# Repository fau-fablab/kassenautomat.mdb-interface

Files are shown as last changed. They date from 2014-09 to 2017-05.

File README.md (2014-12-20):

kassenautomat.mdb-interface
===========================

MDB to USB Interface für Münzwechsler-Ansteuerung

FTDI-Konfiguration
------------------
 * es kommt ein FT232RL zum Einsatz
 * Tool für Linux: https://github.com/mehlis/ft232r_prog.git
 * sonst FT_PROG
 * Linuxzeile: `./ft232r_prog --product 'MDB Interface' --manufacturer 'FAU FabLab' --cbus0 TxLED --cbus1 RxLED --cbus2 Clk12`

Atmel
-----
  * `make fuse` (zur Zeit für external clock via FTDI)
  *  http://www.engbedded.com/fusecalc/
  *  Wenn die Fuses auf externen Takt gesetzt sind, läuft der Chip nur, solange kein USB suspend ist - screen offen halten! (wirklich? nicht jeder hat usb autosuspend an.)
  * `make program`

Sicherung 12V-Schiene
---------------------
  * im worst case sollte eine 5A mtltrg. Sicherung für die 12V-Schiene reichen

Aktueller Stand Platine
-----------------------
  * Kommunikation Atmel <-> PC -> MDB geht, MDB -> PC sollte in rev2 auch gehen.
  * RX- und TX-LEDs am FT232RL gehen nicht (TM)

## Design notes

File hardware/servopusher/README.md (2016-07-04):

servopusher
-----------

The coin-accepting mechanism sometime jams. In this case a lever on top of it has to be pushed.

For this a small system is used which pushes the lever with a servo after the user pushes a switch on the outside of the cash terminal.

After triggering the switch, the microcontroller deactivates the interrupts and drives the servo from position 0 into position 1.
Upon arrival the system starts the return to position 0. Position 0 does not push the lever while position 1 does.

The outside momentary switch is a vandalism safe one with an LED ring. The system could flash the LED ring as a "DONE"-indicator. 

####arduinodruecker
In order to get things done, I have quickly scrambled an Arduino together. The ino-file is in arduinodruecker and self-explinatory.

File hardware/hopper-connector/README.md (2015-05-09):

This is a connector-PCB between coin hopper and mdb-interface-PCB.

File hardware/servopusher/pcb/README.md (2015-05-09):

This directory contains the plans for the PCB.

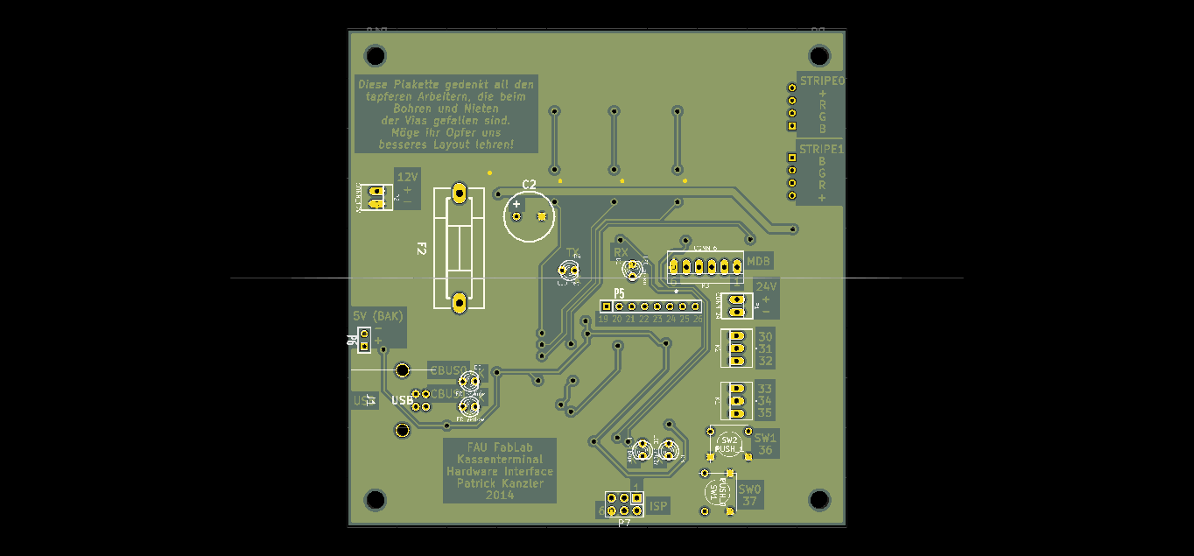
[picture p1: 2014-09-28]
hardware/mdb-interface/plot/cad/mdb-interface_b.png

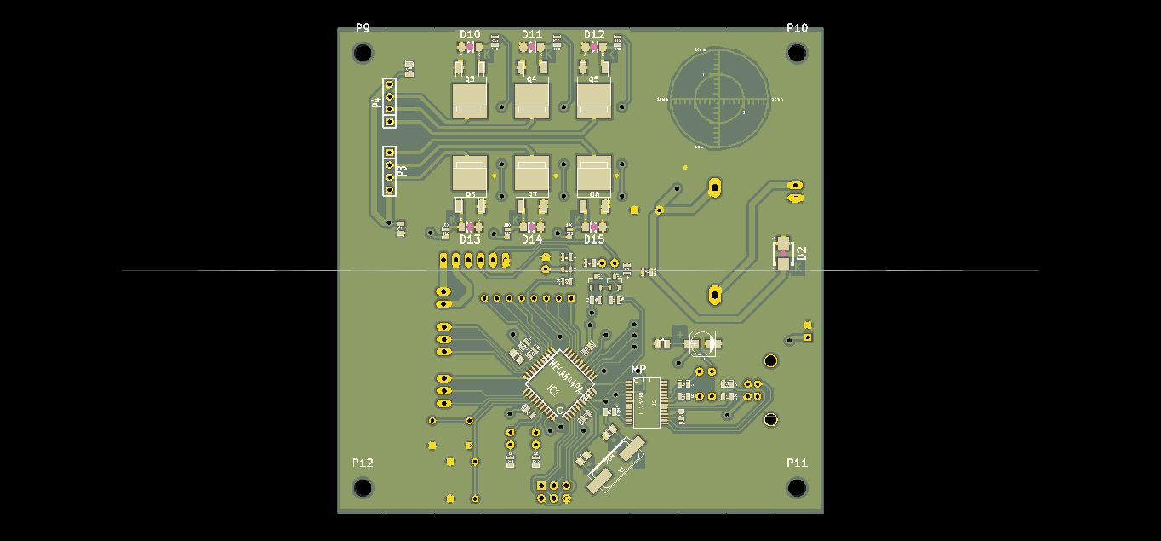
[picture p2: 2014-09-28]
hardware/mdb-interface/plot/cad/mdb-interface_f.png

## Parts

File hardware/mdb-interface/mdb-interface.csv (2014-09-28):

Id | Bezeichner | Gehäuse | Stückzahl | Bezeichnung | Anbieter und Ref
1 | C1 | SMD_Packages:SM0603_Capa | 1 | 10n
2 | C2 | Capacitors_Elko_ThroughHole:Elko_vert_DM10_RM5_CopperClear | 1 | 470u
3 | C3 | Capacitors_SMD:c_elec_5x5.8 | 1 | * 47u 6,3V
4 | C4,C7,C11,C12,C13,C15 | SMD_Packages:SM0603_Capa | 6 | 100n
5 | C5,C14 | Capacitors_SMD:c_0805 | 2 | 1u
6 | C9,C10 | Capacitors_SMD:c_0805 | 2 | 22p
7 | D2 | Diodes_SMD:Diode-SMB_Standard | 1 | SM6T15A
8 | D10,D11,D12,D13,D14,D15 | Diodes_SMD:Diode-MiniMELF_Standard | 6 | ZD5.1
9 | F2 | Fuse_Holders_and_Fuses:Fuseholder5x20_horiz_SemiClosed_Casing10x25mm | 1 | FUSE
10 | ferrite1 | SMD_Packages:SM0603_Resistor | 1 | 0
11 | IC1 | SMD_Packages:TQFP44 | 1 | ATMEGA644PA-A
12 | J1 | Connect:USB_B | 1 | USB
13 | K1,K2 | Connect:PINHEAD1-3 | 2 | *
14 | P1 | Connect:PINHEAD1-2 | 1 | CONN_24
15 | P2 | Connect:PINHEAD1-2 | 1 | CONN_12V
16 | P3 | Connect:PINHEAD1-6 | 1 | CONN_6
17 | P4,P8 | Connect:SIL-4 | 2 | CONN_4
18 | P5 | Connect:SIL-8 | 1 | *
19 | P6 | Connect:SIL-2 | 1 | *
20 | P7 | Pin_Headers:Pin_Header_Straight_2x03 | 1 | CONN_6
21 | P9,P10,P11,P12 | Mounting_Holes:MountingHole_3-7mm | 4 | CONN_1
22 | Q1,Q2 | Transistors_SMD:sot23 | 2 | BCW67
23 | Q3,Q4,Q5,Q6,Q7,Q8 | Mainboard MOSFET:sot428 | 6 | MOSFET_N
24 | R1,R2 | SMD_Packages:SM0603_Resistor | 2 | 10k
25 | R3,R4,R6,R7,R9,R10,R11,R12 | SMD_Packages:SM0603_Resistor | 8 | 1k
26 | R5,R19 | SMD_Packages:SM0603_Resistor | 2 | 10
27 | R8 | SMD_Packages:SM0603_Resistor | 1 | bridge*
28 | R13,R14,R15,R16,R17,R18 | SMD_Packages:SM0603_Resistor | 6 | 100
29 | SW1 | Discret:SW_PUSH_SMALL | 1 | PUSH_0
30 | SW2 | Discret:SW_PUSH_SMALL | 1 | PUSH_1
31 | U1 | SMD_Packages:SSOP28 | 1 | FT232RL
32 | X1 | Crystals_Oscillators_SMD:Q_49U3HMS | 1 | 20M
33 | D1 | LEDs:LED-3MM | 1 | LED green
34 | D4 | LEDs:LED-3MM | 1 | LED red
35 | D6 | LEDs:LED-3MM | 1 | LED orange
36 | D7 | LEDs:LED-3MM | 1 | LED yellow
37 | D8 | LEDs:LED-3MM | 1 | LED amber
38 | D9 | LEDs:LED-3MM | 1 | LED blue
39 | C6,C8 | SMD_Packages:SM0805 | 2 | C
40 | MSC | Measurement_Scales:Gauge_10mm_Type5_CopperTop | 1 | Gauge_10mm_Type5_CopperTop_RevA_Date22Jun2010
41 | MP,MP | Measurement_Points:Measurement_Point_Round-SMD-Pad_Small | 2 | Measurement_Point_Round-SMD-Pad_Small

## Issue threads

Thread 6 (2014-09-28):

Hardware überholen

patkan, 2014-09-28:
Hardware kritisch durchgehen und Fehler finden
korrigieren, falls mal eine neue Revision produziert wird

die ISP-Beschaltung ist etwas dünn? (könnte robuster)
AVR-Beschaltung zu instabil?

patkan, 2015-01-18:
Dahingehend passt alles....

Closed 2015-01-18.

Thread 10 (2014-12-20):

MDB RX Pullup falsch

mgmax, 2014-12-20:
Die Widerstände an MDB_MR, die nach GND gehen, müssen nach VCC. D.h. R3 R4 D1 spiegeln. D1 dann richtigrum.

patkan, 2015-01-18:
Hi @mgmax meintest du mit "D1 dann richtigrum", dass D1 von VCC nach Busleitung zeigen soll? Ich nehme mal an ja...

mgmax, 2015-01-18:
Ja. MDB_MR ist an der Gegenstelle ein open collector Ausgang, ich hab
das grad nochmal in der Spec nachgeschaut.

mgmax, 2015-01-18:
passt so, Danke!

Closed 2015-01-18.

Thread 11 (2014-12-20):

erster Prototyp kann weg

mgmax, 2014-12-20:
da sind lauter Vias kaputt. Nichtmal die 5V geht gescheit. -> Bitte Issues beheben und dann zum Fertiger geben.

patkan, 2015-01-18:
Dieses Issue wird erst geschlossen, wenn #9  erledigt ist und die Platine an den aktuellen Schaltplan angepasst.

Closed 2015-01-18.

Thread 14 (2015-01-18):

Montageplatte passt nicht zu Befestigungslöchern

mgmax, 2015-01-18:
Nur so als Notiz: Das jetzige Befestigungs-Acrylstück hat unpassende (wenige mm falsch) Lochabstände und muss entsorgt und neu gefertigt werden.

Die Platine sollte einen Lochabstand haben, der eine schöne Zahl ist, z.B. 90x90 mm oder so. Wenn Platz ist, kann man den gleich mit draufschreiben.

Closed 2015-01-18.

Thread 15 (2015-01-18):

Platine für die Fertigung vorbereiten

patkan, 2015-01-18:
Da ich noch keine Erfahrung mit der Vorbereitung einer Platine auf die professionelle Fertigung habe, müsste das bitte @Virtex7 übernehmen.
Noch zu tun:
* prüfen, ob Fehler vorliegen
* DRC auf Richtigkeit prüfen und nochmal ausführen (abhängig vom Fertiger)
* Vias sind fürs Lab? Muss man die für den Fertiger anpassen?
* evtl noch Beschriftungen anpassen
* Fertiger stehen in #11
@Virtex7 müsste commit-Rechte für dieses Repo haben.

Für Rückfragen stehe ich jederzeit zur Verfügung. Mich würde dann interessieren, ob ich irgendwas grob falsch gemacht habe :-)
Vielen Dank
Patrick

Closed 2015-05-12.

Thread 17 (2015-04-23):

Hopper mit anbinden

mgmax, 2015-04-23:
überlegen, ob über Extension-Connector und passenden Code nicht doch der Hopper hier mit reingewurschtelt werden kann.

patkan, 2015-05-05:
Mögliche Hardware-Lösung in 7660acf133c8e678a42cc5fb0fed4c759e9ff4b8
Bitte anschauen

mgmax, 2015-05-12:
Firmware ist vorbereitet (hopper-task zur Zeit noch deaktiviert), am Schaltplan noch zu tun:
- [ ] Sicherungswerte anpassen
- [ ] C2 hat als Wert 2200, da fehlt noch ein "µ", es sei denn das sind wirklich Farad...

Ansonsten:
- [ ] nachschauen ob der Hopper ein 24V Typ ist
- [ ] Netzteil Reichelt 24V mit genug Saft wäre:  https://www.reichelt.de/SNT-RS-150-24/3/index.html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
      Das passt laut CAD auch noch gerade so hinter den Münzer hin ohne mit dem LAN-Kabel zu kollidieren., ggf müssen wir die MDB Platine hinter den Geldscheiner tun und das Netzteil
- [ ] sonstiges Hühnerfutter für Platine

mgmax, 2015-05-12:
- [ ] Transil umbauen auf  P6SMB 33A SMD (war grad lieferbar, außerdem ist 24 zu knapp)
-  [ ] Warenkorb weiterbasteln, Entwurf: https://secure.reichelt.de/index.html?&ACTION=20&LA=5010&AWKID=1066589&PROVID=2084

mgmax, 2015-05-12:
- [ ] R2 brennt durch, P=0.5W!

mgmax, 2015-05-26:
selbstklebende Abstandshalter (eher teuer, aber was solls): https://www.reichelt.de/AHS-15-9/3/index.html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
brauchen aber 4mm Platinenlöcher

mgmax, 2015-05-31:
Warenkorb ist jetzt im ERP

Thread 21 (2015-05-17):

neu flashen und LED-Stecker umtauschen

mgmax, 2015-05-17:
im git ist bereits eine Änderung, die noch nicht  auf die Platine geflasht wurde:
RGB-Anschlüsse 0 und 1 tauschen, damit die Reihenfolge zur Steckerbeschriftung passt
Dementsprechend muss man beim nächsten Flashen die Stecker umtauschen.

mgmax, 2015-07-07:
auch erledigt, neu geflasht.

Closed 2015-07-07.

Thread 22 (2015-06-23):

timer overrun

mgmax, 2015-06-23:
irgendwie haben die Tasks doch mal zu lange gebraucht... -> Durchlaufzeit erhöhen?

mgmax, 2015-06-24:
man müsste mal messen (LED_AMBER an = idle zeit am ende des taktes), wie groß gerade die CPU-Load ist, und die FW neu flashen und schauen ob es besser wird.

mgmax, 2015-07-07:
behoben.

Closed 2015-07-07.

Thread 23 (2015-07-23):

Servopusher: zweiter Eingang für Auslösung durch Software

patkan, 2015-07-23:
Die Kassenterminalsoftware sollte die Möglichkeit haben den Servopusher auszulösen, da der MDB "Coin Jam" melden kann. Am besten sollte dieser Eingang per Optokoppler abgetrennt sein, um nicht irgendwelche Masseschleifen zu bauen.

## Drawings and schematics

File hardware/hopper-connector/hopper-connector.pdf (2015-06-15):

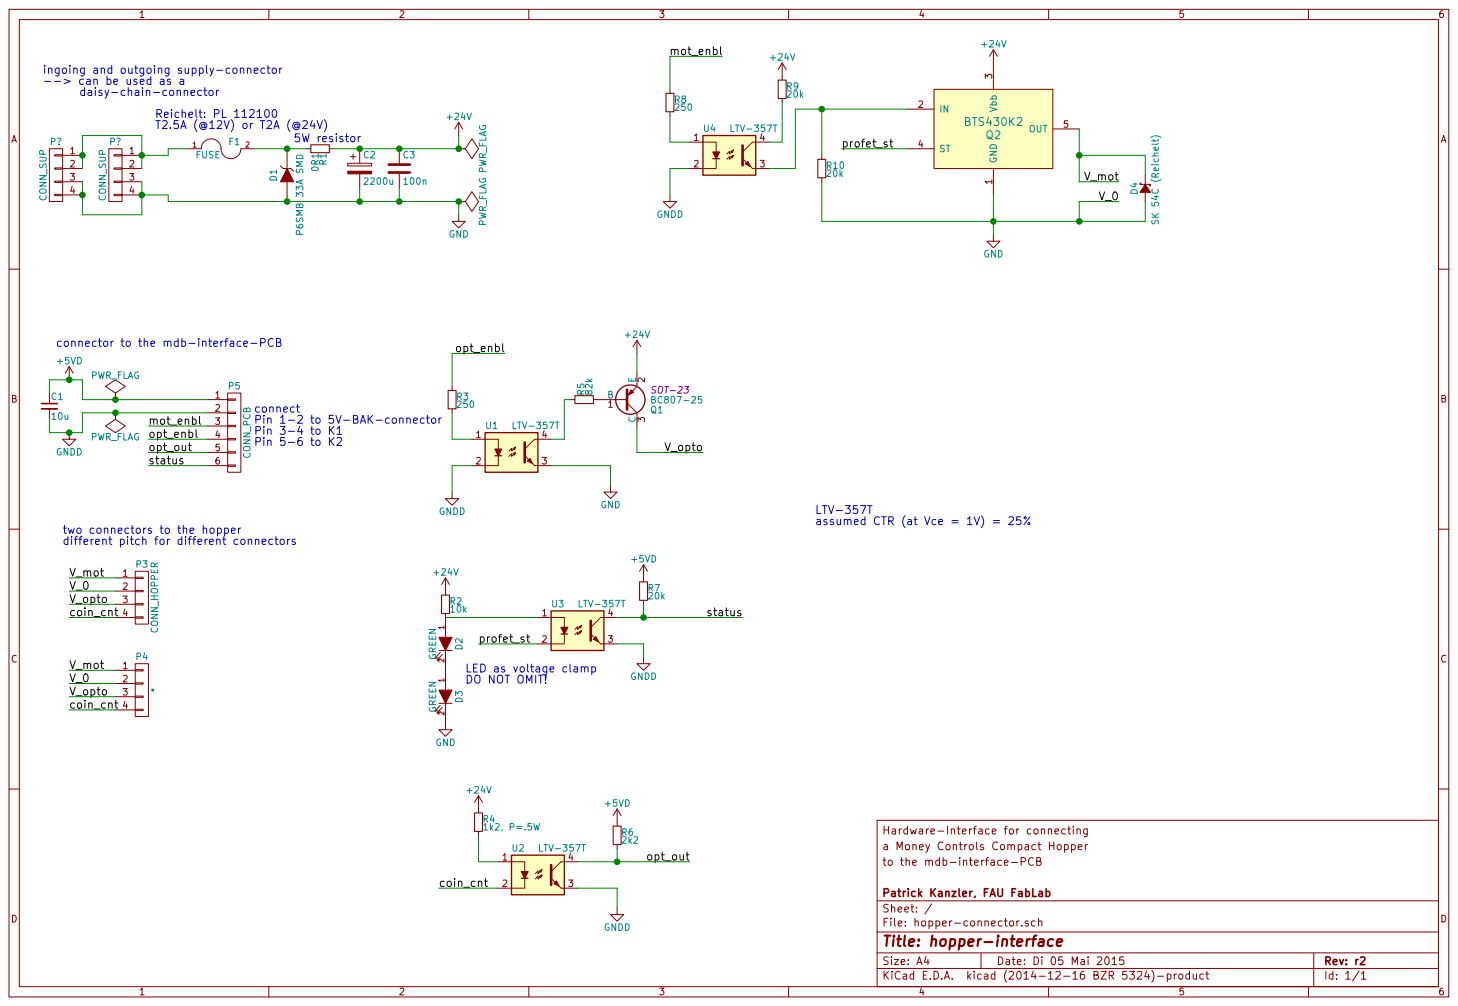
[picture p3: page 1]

5W resistor connect Pin 1-2 to 5V-BAK-connector Pin 3-4 to K1 Pin 5-6 to K2

ingoing and outgoing supply-connector
--> can be used as a

connector to the mdb-interface-PCB

assumed CTR (at Vce = 1V) = 25%

two connectors to the hopper
different pitch for different connectors

LED as voltage clamp

Hardware-Interface for connecting
a Money Controls Compact Hopper
to the mdb-interface-PCB

File: hopper-connector.sch Sheet: / Patrick Kanzler, FAU FabLab

Id: 1/1 Title: hopper-interface

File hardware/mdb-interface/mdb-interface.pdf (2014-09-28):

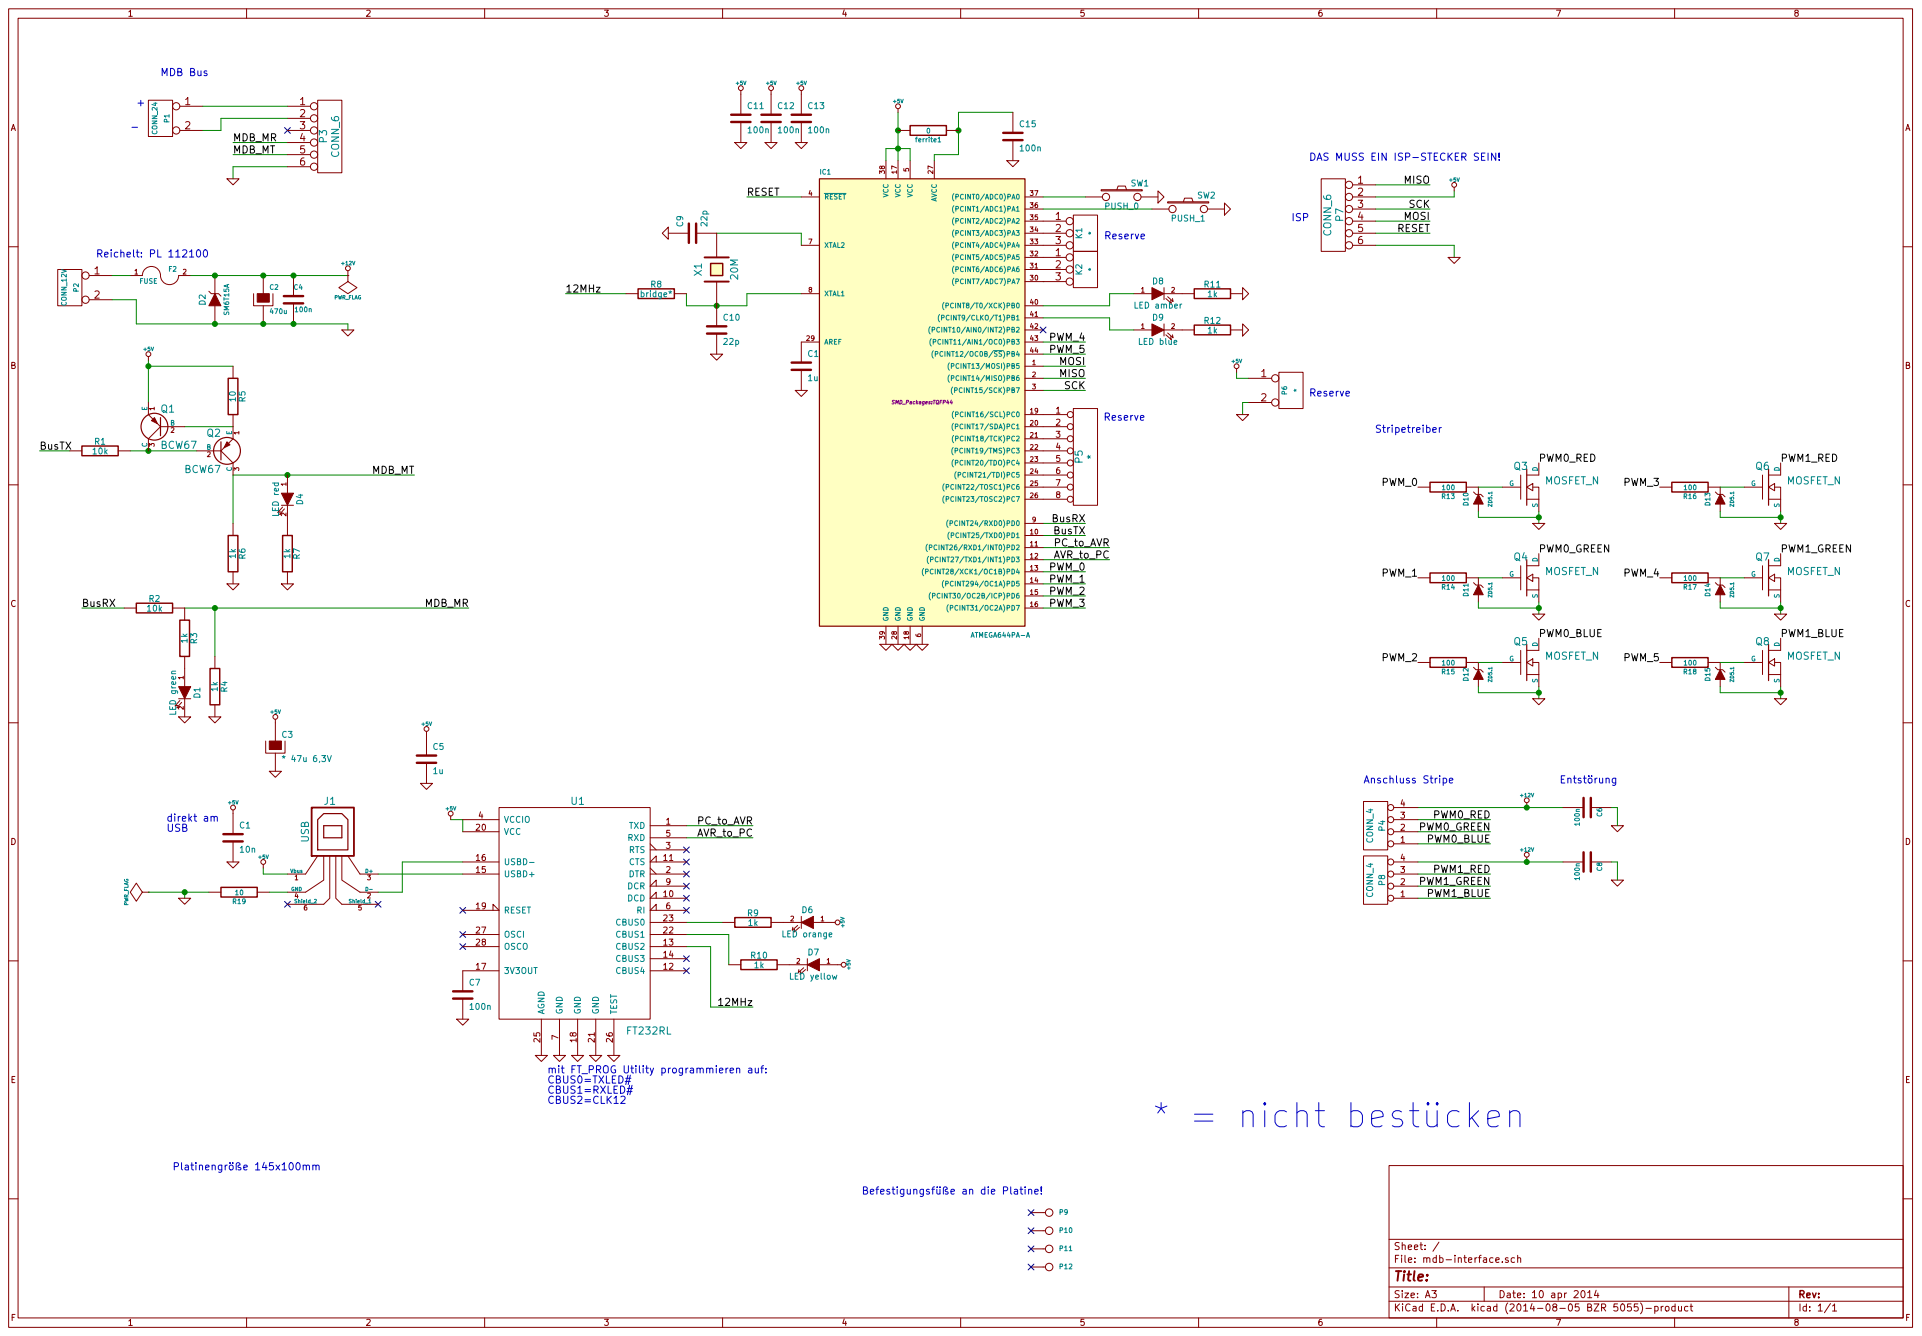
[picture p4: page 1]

12MHz mit FT_PROG Utility programmieren auf:

DAS MUSS EIN ISP-STECKER SEIN!

7 DCR 9 DCD 10 VCC 20 CTS 11 GND 21 CBUS4 12 CBUS1 22 CBUS2 13 CBUS0 23 CBUS3 14 USBD+ 15 AGND 25 USBD- 16 TEST 26

Id: 1/1 Title: File: mdb-interface.sch Sheet: / * = nicht bestücken

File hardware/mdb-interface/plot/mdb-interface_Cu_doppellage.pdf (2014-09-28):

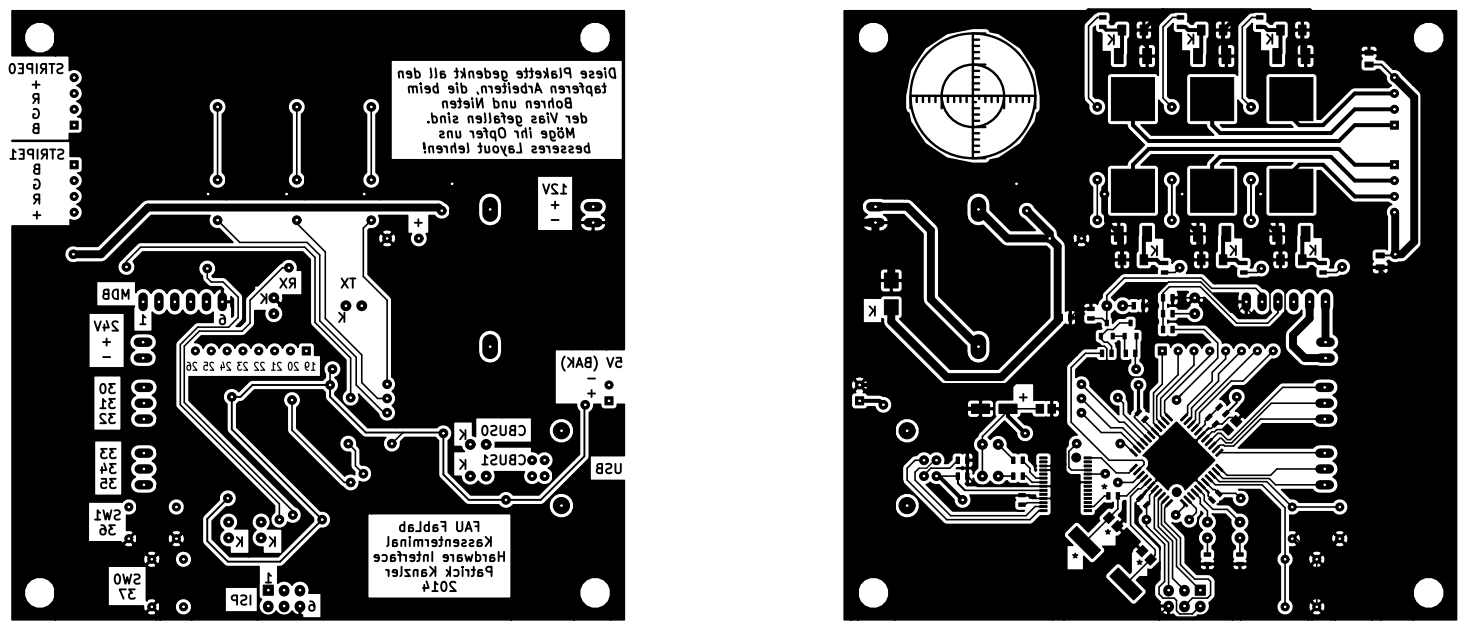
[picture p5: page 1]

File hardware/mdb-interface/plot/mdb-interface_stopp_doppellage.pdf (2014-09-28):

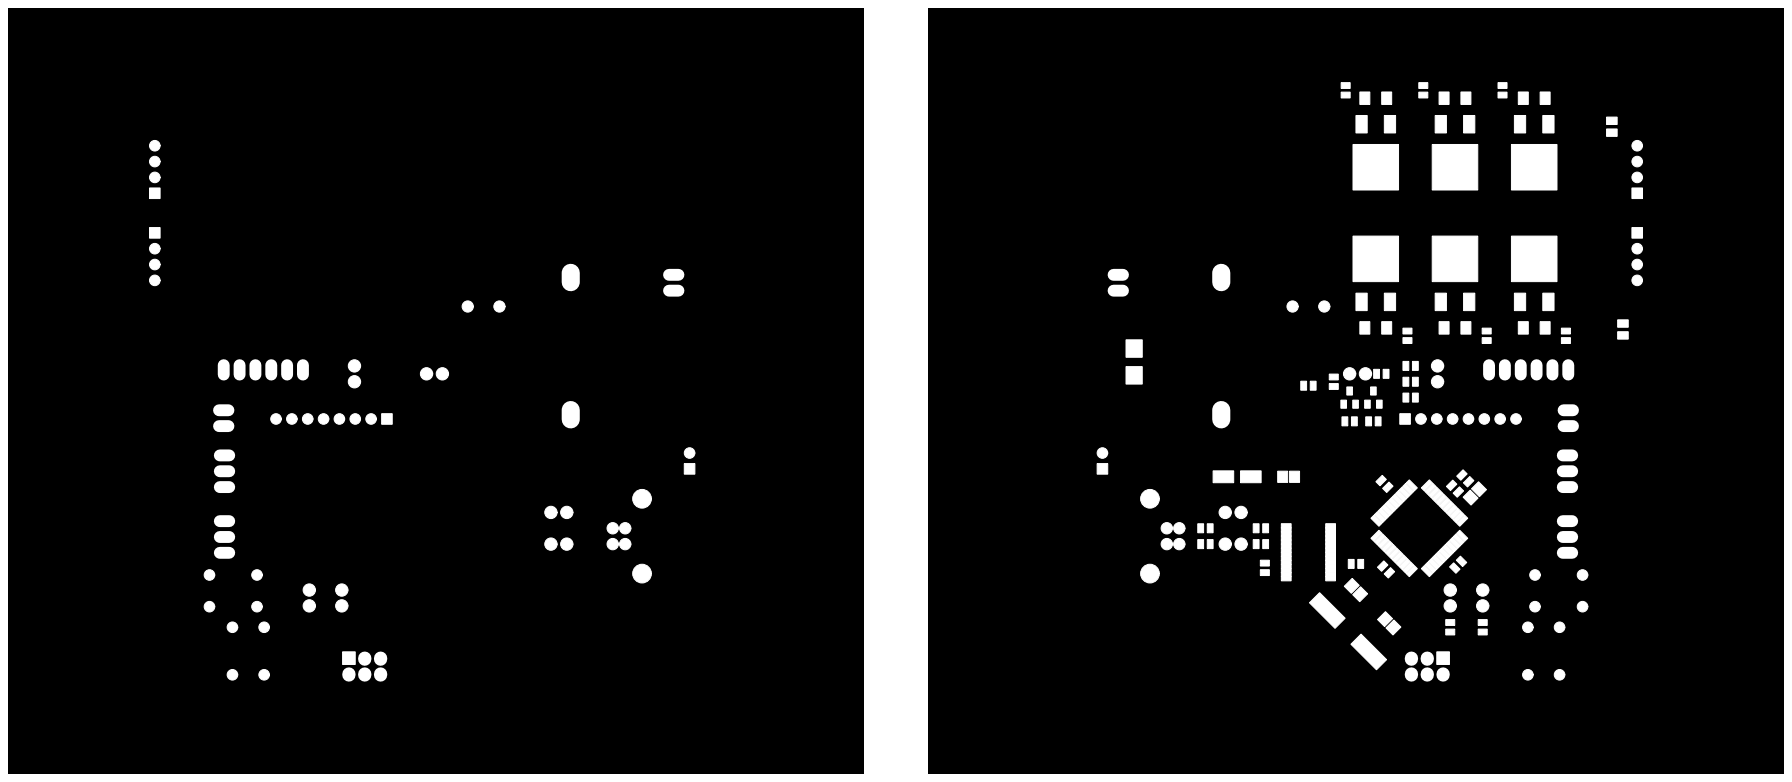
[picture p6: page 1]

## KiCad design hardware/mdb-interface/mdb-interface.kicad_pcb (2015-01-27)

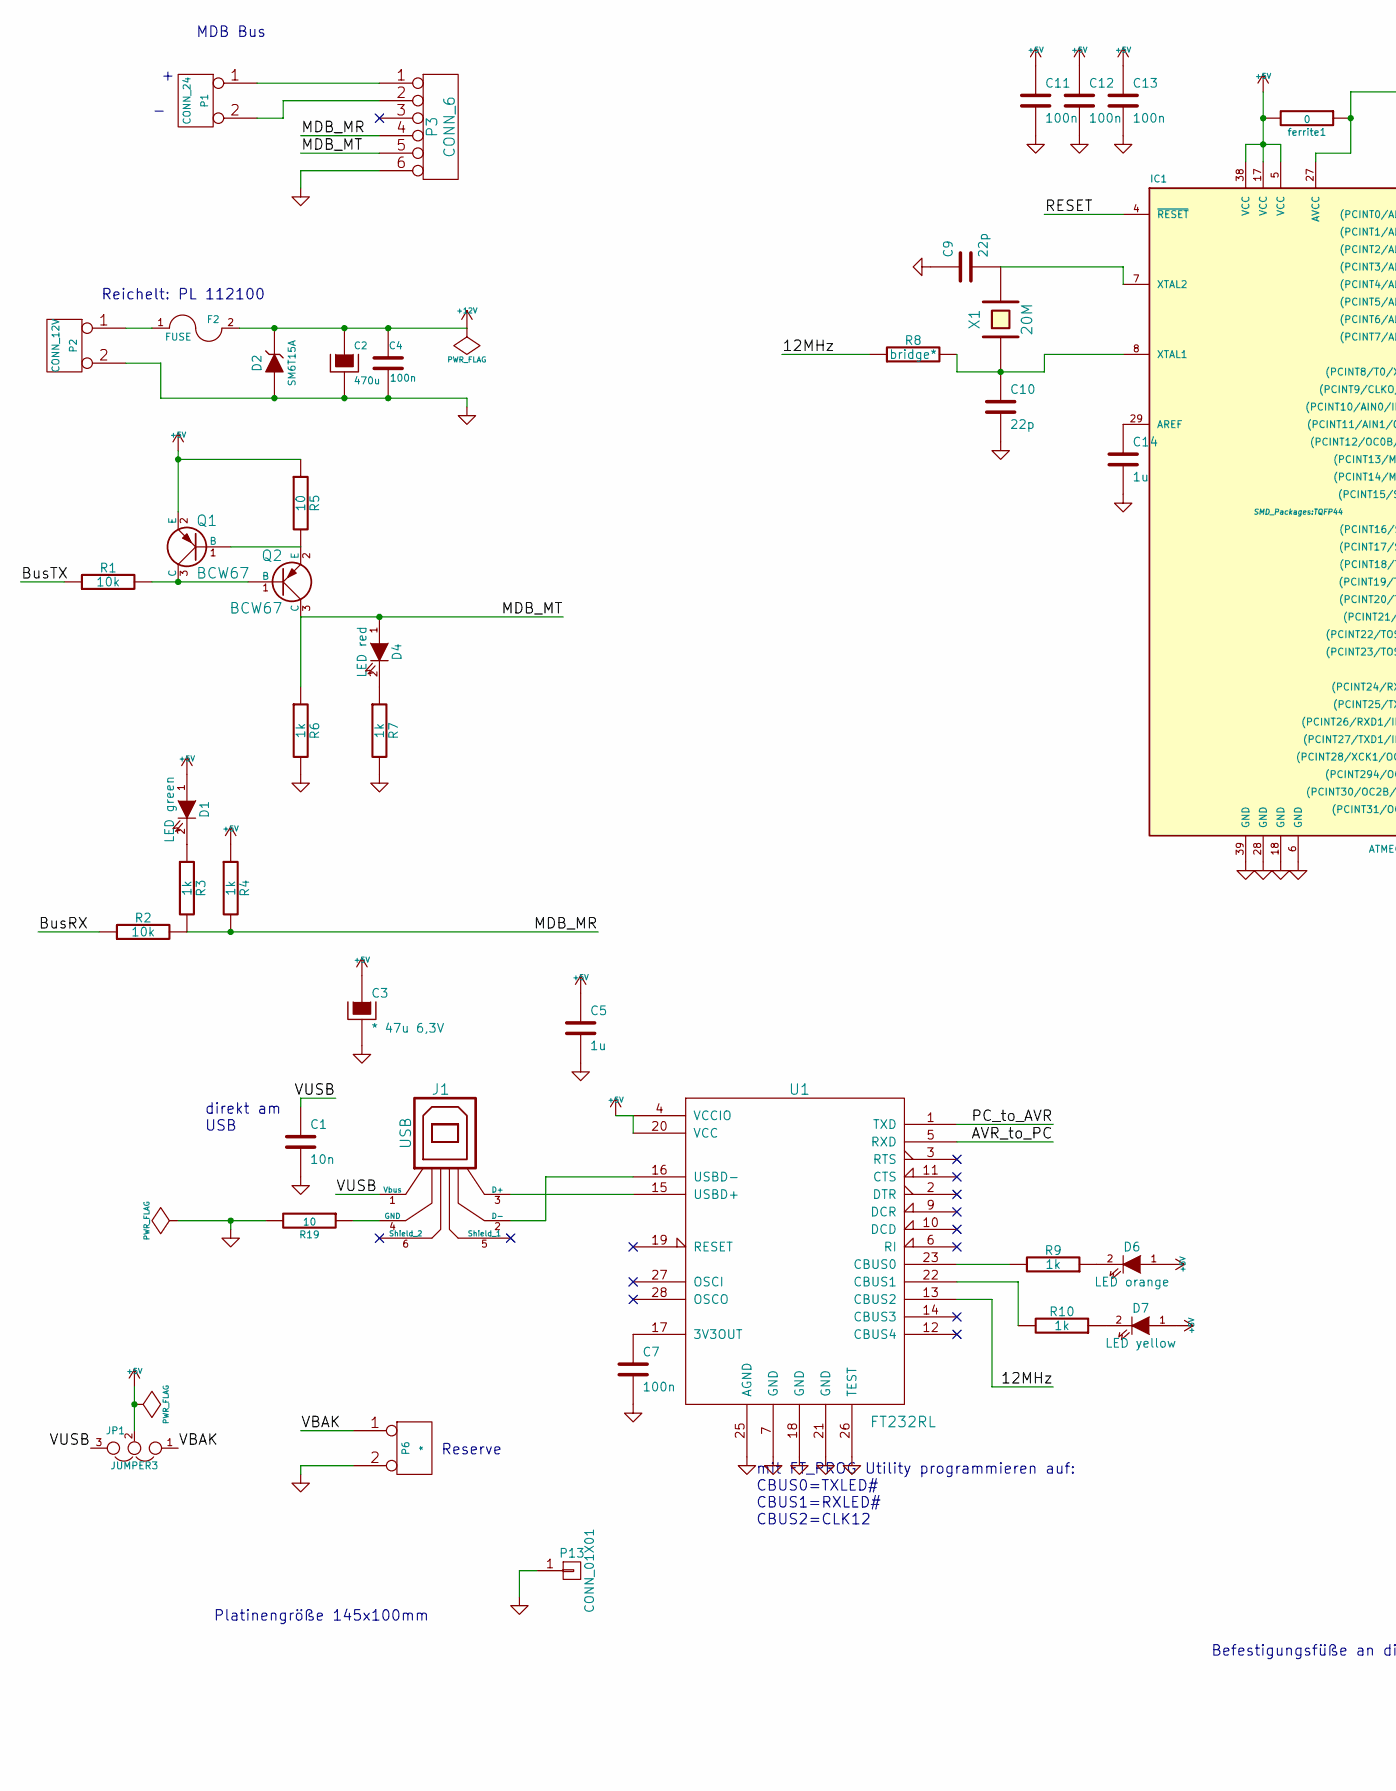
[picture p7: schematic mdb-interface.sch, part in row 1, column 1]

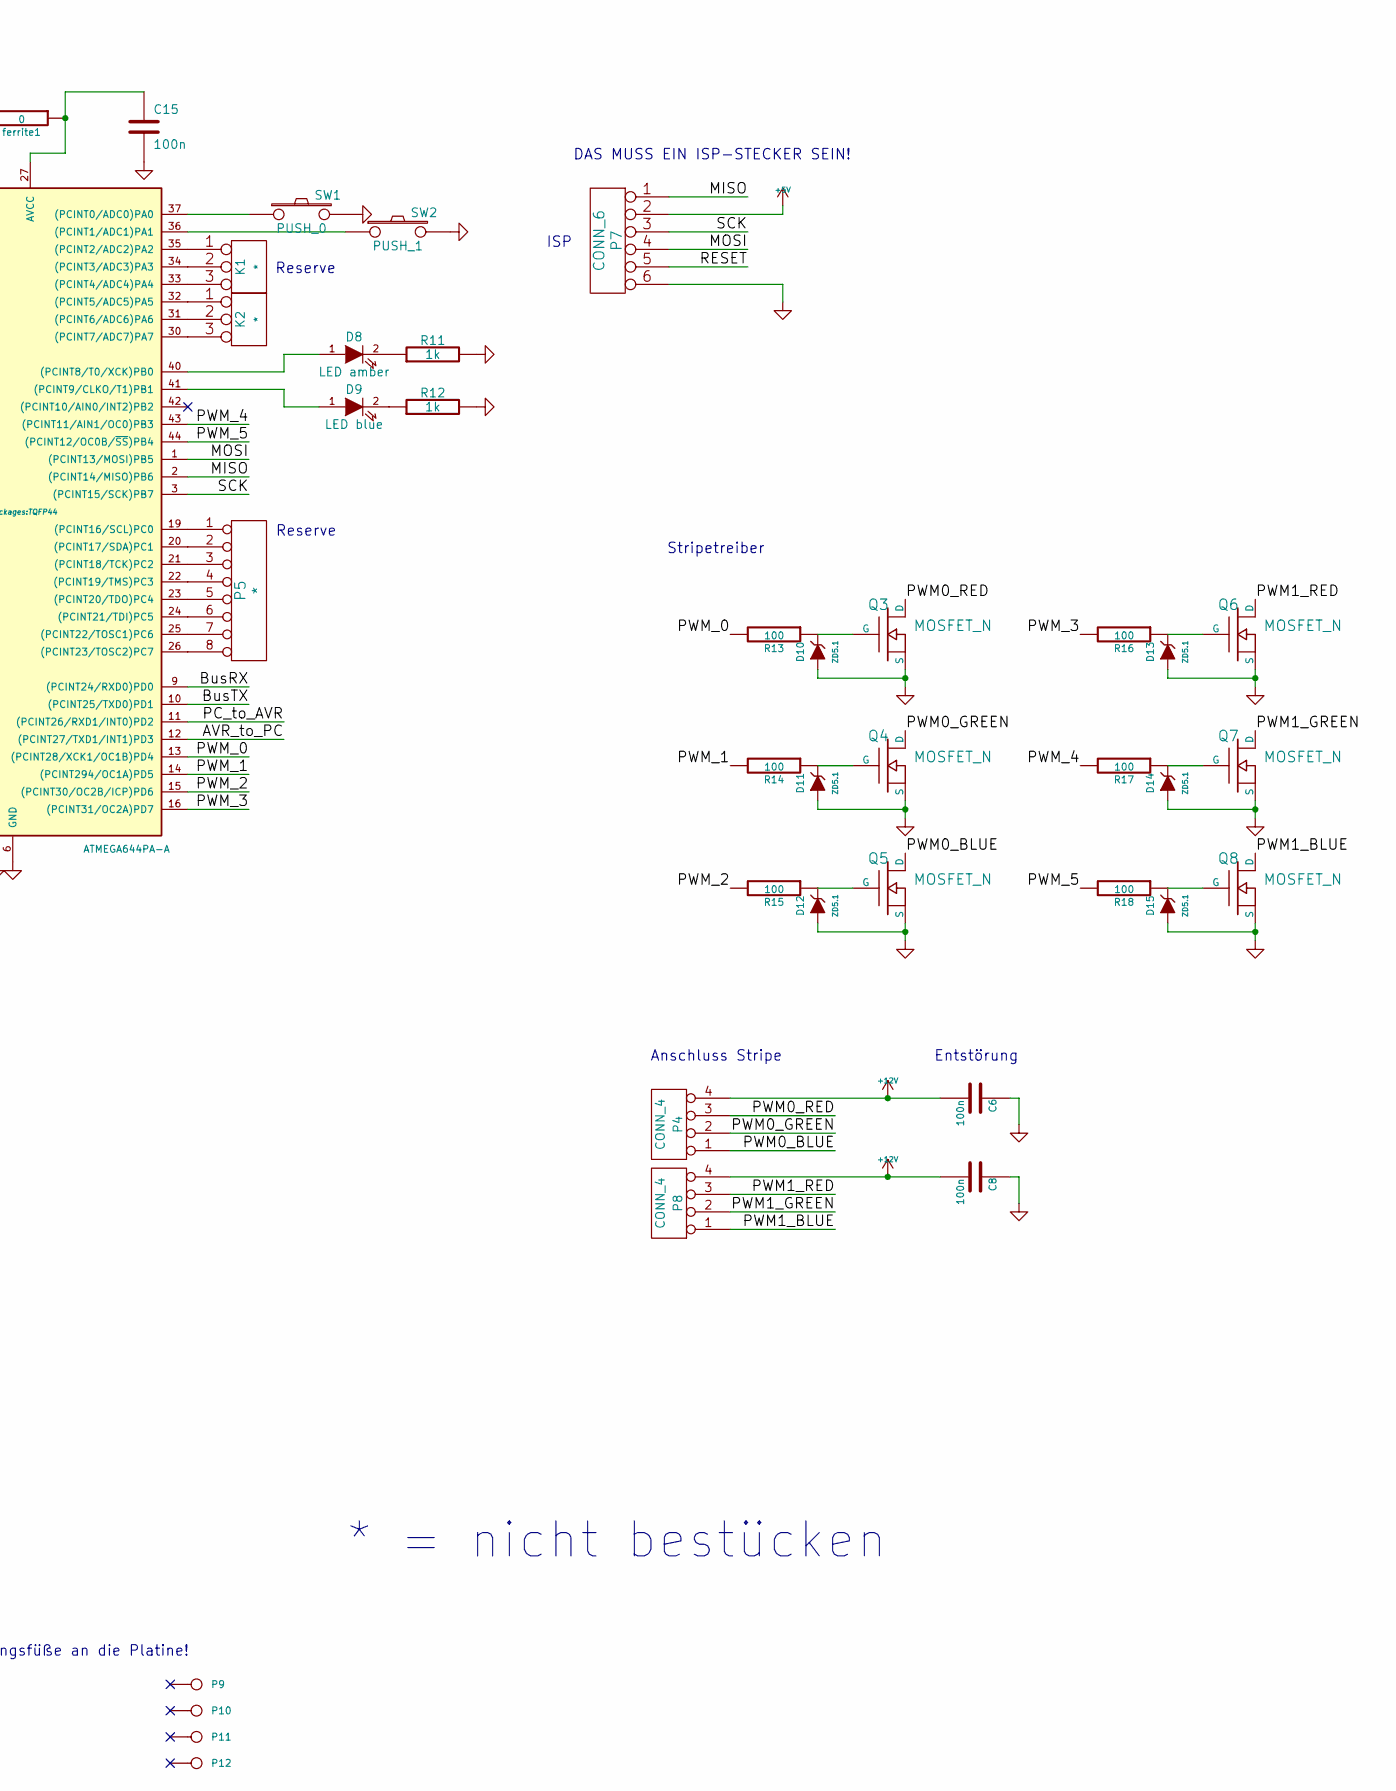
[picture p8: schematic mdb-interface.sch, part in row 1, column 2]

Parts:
C1: 10n; SM0603_Capa
C2: 470u; Elko_vert_DM10_RM5_CopperClear
C3: * 47u 6,3V; c_elec_5x5.8
C4, C7, C11, C12, C13, C15: 100n; SM0603_Capa
C5, C14: 1u; c_0805
C6, C8: 100n; SM0805
C9, C10: 22p; c_0805
D1: LED green; LED-3MM
D2: SM6T15A; Diode-SMB_Standard
D4: LED red; LED-3MM
D6: LED orange; LED-3MM
D7: LED yellow; LED-3MM
D8: LED amber; LED-3MM
D9: LED blue; LED-3MM
D10, D11, D12, D13, D14, D15: ZD5.1; Diode-MiniMELF_Standard
F2: FUSE; Fuseholder5x20_horiz_SemiClosed_Casing10x25mm
IC1: ATMEGA644PA-A; TQFP44
J1: USB; USB_B
JP1: JUMPER3; NetTie-II_SMD
K1, K2: *; PINHEAD1-3
P1: CONN_24; PINHEAD1-2
P2: CONN_12V; PINHEAD1-2
P3: CONN_6; PINHEAD1-6
P4, P8: CONN_4; SIL-4
P5: *; SIL-8
P6: *; SIL-2
P7: CONN_6; Pin_Header_Straight_2x03
P9, P10, P11, P12: CONN_1; MountingHole_3-7mm
P13: CONN_01X01; Measurement_Point_Square-TH_Small
Q1, Q2: BCW67; sot23
Q3, Q4, Q5, Q6, Q7, Q8: MOSFET_N; sot428
R1, R2: 10k; SM0603_Resistor
R3, R4, R6, R7, R9, R10, R11, R12: 1k; SM0603_Resistor
R5, R19: 10; SM0603_Resistor
R8: bridge*; SM0603_Resistor
R13, R14, R15, R16, R17, R18: 100; SM0603_Resistor
SW1: PUSH_0; SW_PUSH_SMALL
SW2: PUSH_1; SW_PUSH_SMALL
U1: FT232RL; SSOP28
X1: 20M; Q_49U3HMS
ferrite1: 0; SM0603_Resistor

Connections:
+5V: C3.1, C5.1, C11.1, C12.1, C13.1, D1.1 (A), D6.1 (A), D7.1 (A), IC1.5 (VCC), IC1.17 (VCC), IC1.38 (VCC), JP1.2, P7.2, Q1.2 (E), R4.1, R5.1, U1.4 (VCCIO), U1.20 (VCC), ferrite1.2
+12V: C2.1, C4.1, C6.2, C8.2, D2.2 (K), F2.2, P4.4, P8.4
/12MHz: R8.1, U1.13 (CBUS2)
/AVR_to_PC: IC1.12 ((PCINT27/TXD1/INT1)PD3), U1.5 (RXD)
/BusRX: IC1.9 ((PCINT24/RXD0)PD0), R2.1
/BusTX: IC1.10 ((PCINT25/TXD0)PD1), R1.1
/MDB_MR: P3.4, R2.2, R3.2, R4.2
/MDB_MT: D4.1 (A), P3.5, Q2.3 (C), R6.1
/MISO: IC1.2 ((PCINT14/MISO)PB6), P7.1
/MOSI: IC1.1 ((PCINT13/MOSI)PB5), P7.4
/PC_to_AVR: IC1.11 ((PCINT26/RXD1/INT0)PD2), U1.1 (TXD)
/PWM0_BLUE: P4.1, Q5.D
/PWM0_GREEN: P4.2, Q4.D
/PWM0_RED: P4.3, Q3.D
/PWM1_BLUE: P8.1, Q8.D
/PWM1_GREEN: P8.2, Q7.D
/PWM1_RED: P8.3, Q6.D
/PWM_0: IC1.13 ((PCINT28/XCK1/OC1B)PD4), R13.2
/PWM_1: IC1.14 ((PCINT294/OC1A)PD5), R14.2
/PWM_2: IC1.15 ((PCINT30/OC2B/ICP)PD6), R15.2
/PWM_3: IC1.16 ((PCINT31/OC2A)PD7), R16.2
/PWM_4: IC1.43 ((PCINT11/AIN1/OC0)PB3), R17.2
/PWM_5: IC1.44 ((PCINT12/OC0B/~SS~)PB4), R18.2
/RESET: IC1.4 (~RESET), P7.5
/SCK: IC1.3 ((PCINT15/SCK)PB7), P7.3
/VBAK: JP1.1, P6.1
/VUSB: C1.1, J1.1 (Vbus), JP1.3
GND: C1.2, C2.2, C3.2, C4.2, C5.2, C6.1, C7.2, C8.1, C9.1, C10.2, C11.2, C12.2, C13.2, C14.2, C15.2, D2.1 (A), D10.1 (A), D11.1 (A), D12.1 (A), D13.1 (A), D14.1 (A), D15.1 (A), IC1.6 (GND), IC1.18 (GND), IC1.28 (GND), IC1.39 (GND), P2.2 (PM), P3.6, P6.2 (PM), P7.6, P13.1, Q3.S, Q4.S, Q5.S, Q6.S, Q7.S, Q8.S, R6.2, R7.2, R11.2, R12.2, R19.2, SW1.2, SW2.2, U1.7 (GND), U1.18 (GND), U1.21 (GND), U1.25 (AGND), U1.26 (TEST)
unnamed: C7.1, U1.17 (3V3OUT)
unnamed: C9.2, IC1.7 (XTAL2), X1.2
unnamed: C10.1, IC1.8 (XTAL1), R8.2, X1.1
unnamed: C14.1, IC1.29 (AREF)
unnamed: C15.1, IC1.27 (AVCC), ferrite1.1
unnamed: D1.2 (K), R3.1
unnamed: D4.2 (K), R7.1
unnamed: D6.2 (K), R9.1
unnamed: D7.2 (K), R10.1
unnamed: D8.1 (A), IC1.40 ((PCINT8/T0/XCK)PB0)
unnamed: D8.2 (K), R11.1
unnamed: D9.1 (A), IC1.41 ((PCINT9/CLKO/T1)PB1)
unnamed: D9.2 (K), R12.1
unnamed: D10.2 (K), Q3.G, R13.1
unnamed: D11.2 (K), Q4.G, R14.1
unnamed: D12.2 (K), Q5.G, R15.1
unnamed: D13.2 (K), Q6.G, R16.1
unnamed: D14.2 (K), Q7.G, R17.1
unnamed: D15.2 (K), Q8.G, R18.1
unnamed: F2.1, P2.1
unnamed: IC1.19 ((PCINT16/SCL)PC0), P5.1
unnamed: IC1.20 ((PCINT17/SDA)PC1), P5.2
unnamed: IC1.21 ((PCINT18/TCK)PC2), P5.3
unnamed: IC1.22 ((PCINT19/TMS)PC3), P5.4
unnamed: IC1.23 ((PCINT20/TDO)PC4), P5.5
unnamed: IC1.24 ((PCINT21/TDI)PC5), P5.6
unnamed: IC1.25 ((PCINT22/TOSC1)PC6), P5.7
unnamed: IC1.26 ((PCINT23/TOSC2)PC7), P5.8
unnamed: IC1.30 ((PCINT7/ADC7)PA7), K2.3
unnamed: IC1.31 ((PCINT6/ADC6)PA6), K2.2 (PM)
unnamed: IC1.32 ((PCINT5/ADC5)PA5), K2.1
unnamed: IC1.33 ((PCINT4/ADC4)PA4), K1.3
unnamed: IC1.34 ((PCINT3/ADC3)PA3), K1.2 (PM)
unnamed: IC1.35 ((PCINT2/ADC2)PA2), K1.1
unnamed: IC1.36 ((PCINT1/ADC1)PA1), SW2.1
unnamed: IC1.37 ((PCINT0/ADC0)PA0), SW1.1
unnamed: J1.2 (D-), U1.16 (USBD-)
unnamed: J1.3 (D+), U1.15 (USBD+)
unnamed: J1.4 (GND), R19.1
unnamed: P1.1, P3.1
unnamed: P1.2 (PM), P3.2
unnamed: Q1.1 (B), Q2.2 (E), R5.2
unnamed: Q1.3 (C), Q2.1 (B), R1.2
unnamed: R9.2, U1.23 (CBUS0)
unnamed: R10.2, U1.22 (CBUS1)

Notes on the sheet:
* = nicht bestücken
ISP
Reserve
mit FT_PROG Utility programmieren auf: CBUS0=TXLED# CBUS1=RXLED# CBUS2=CLK12
direkt am USB
MDB Bus
Stripetreiber
Anschluss Stripe
Reichelt: PL 112100
Befestigungsfüße an die Platine!
DAS MUSS EIN ISP-STECKER SEIN!
Platinengröße 145x100mm
Entstörung

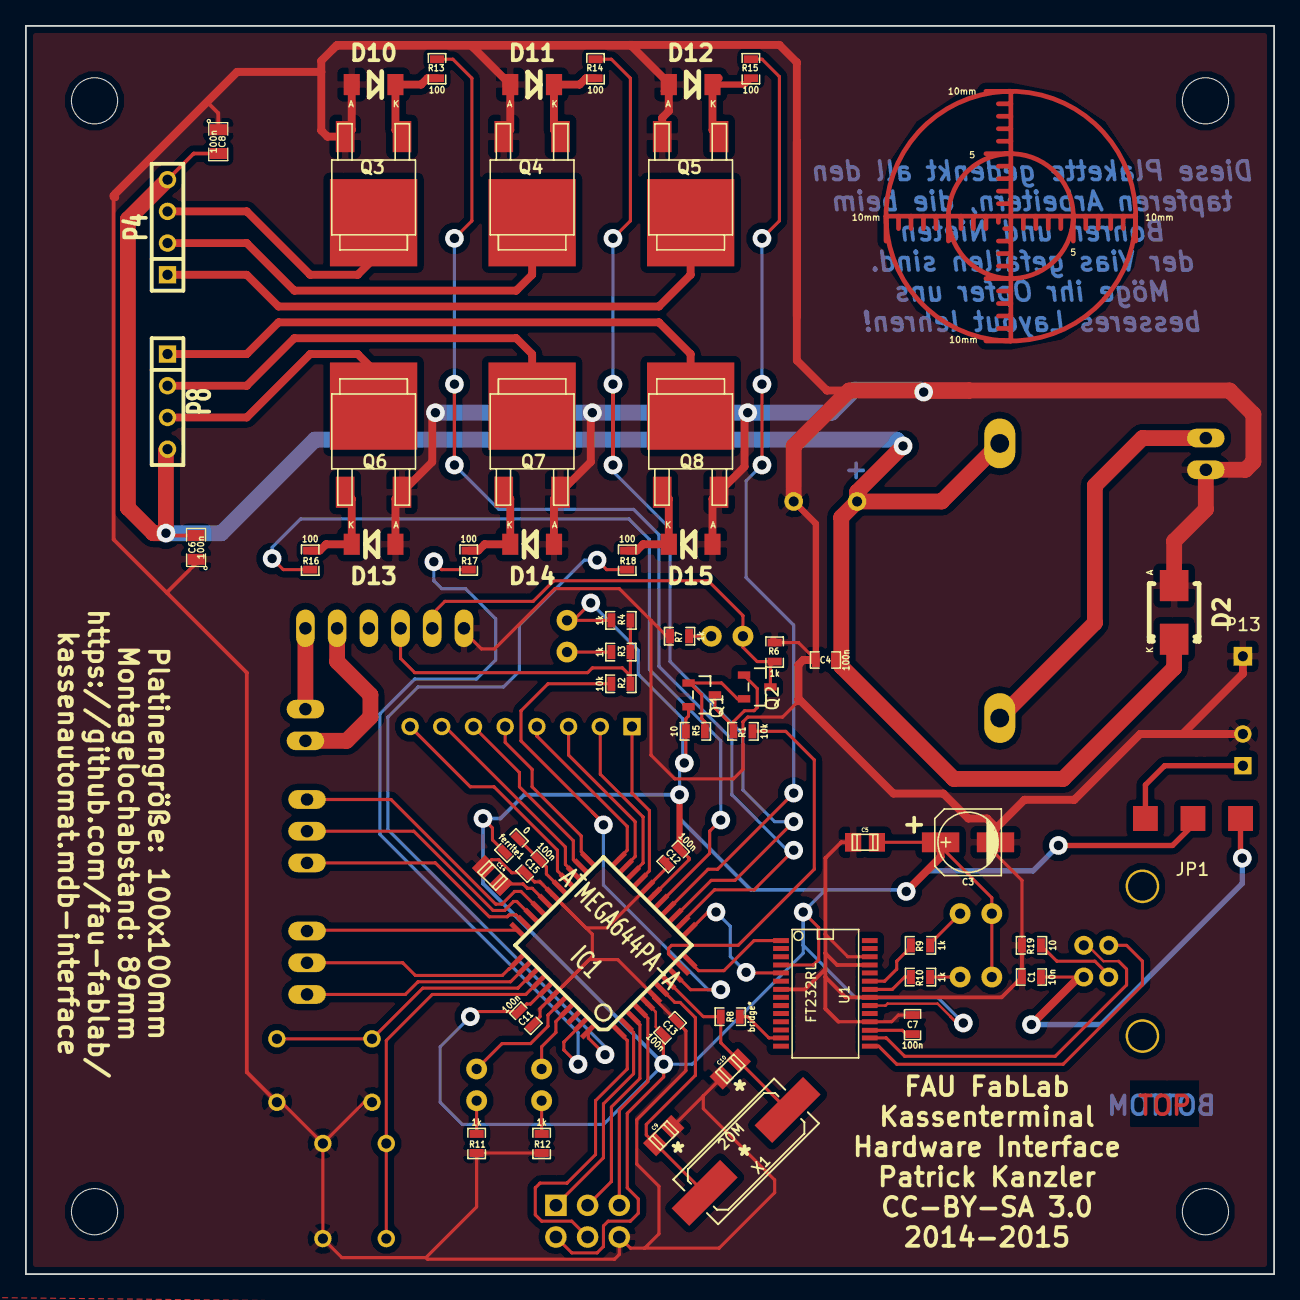
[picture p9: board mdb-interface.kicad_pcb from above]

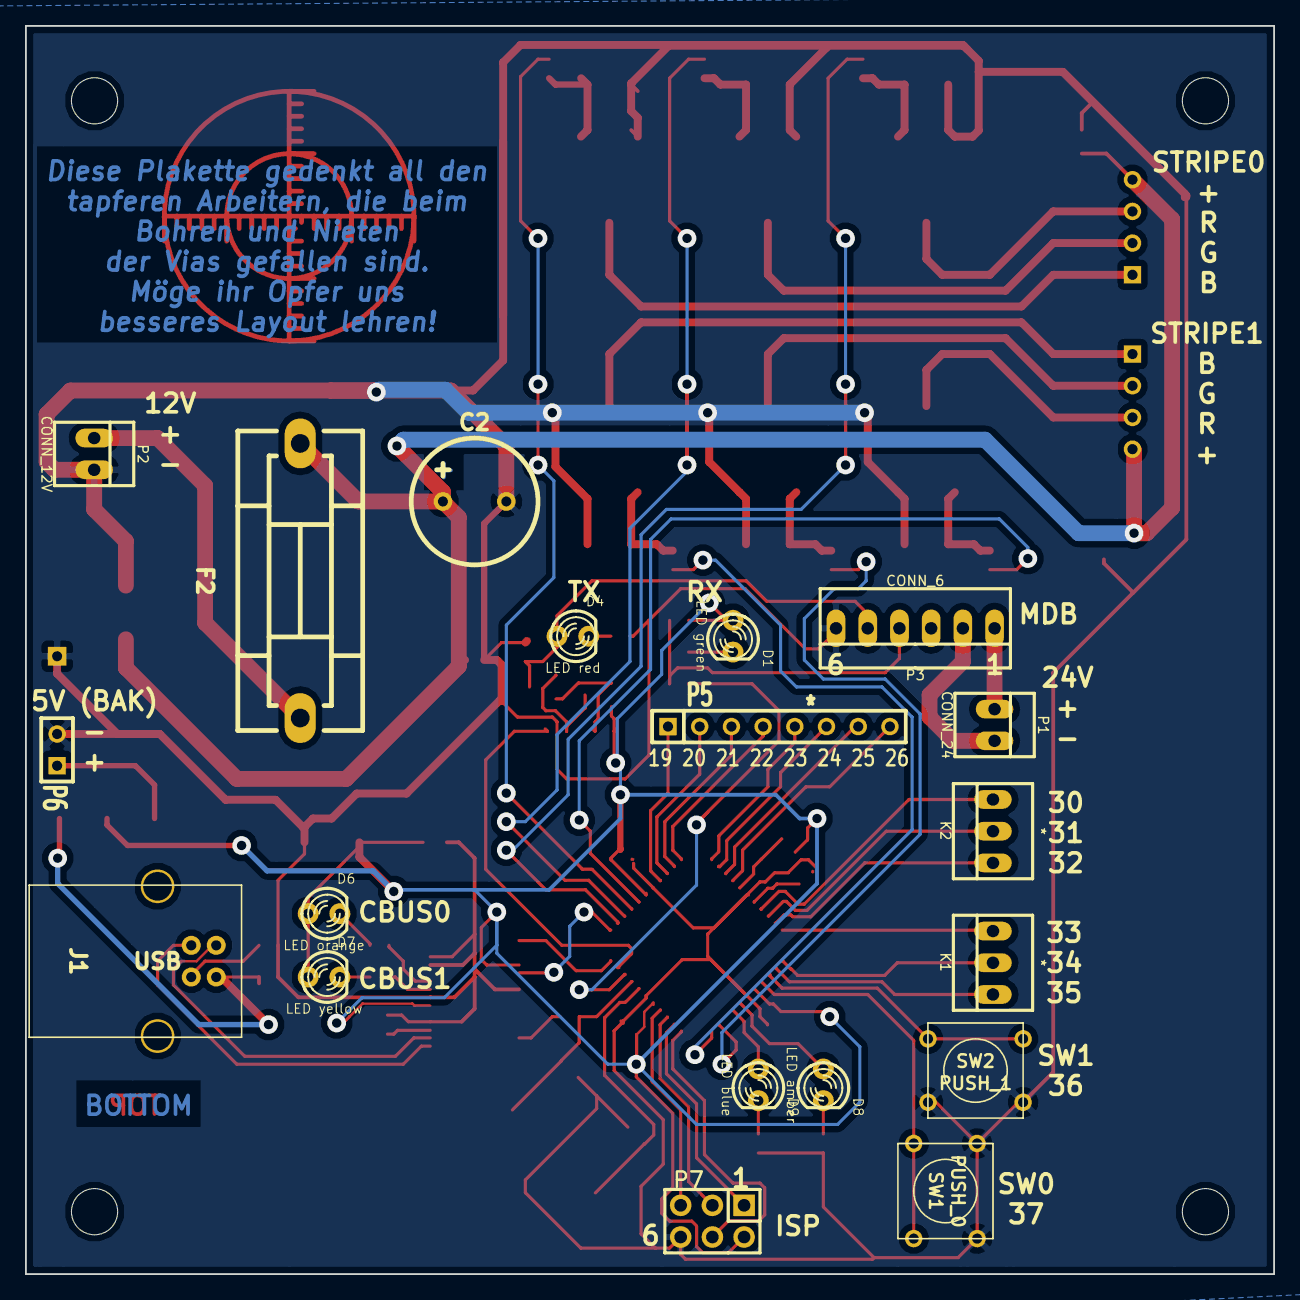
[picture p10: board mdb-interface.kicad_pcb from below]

Board: 2 copper layers, 100.0 x 100.0 mm, 80 parts (19 on the bottom side), 73 nets.

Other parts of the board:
MSC: Gauge_10mm_Type5_CopperTop_RevA_Date22Jun2010; Gauge_10mm_Type5_CopperTop

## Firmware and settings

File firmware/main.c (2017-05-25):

/*
 *    Filename: main.c
 * Description: bus interface between PC and MDB-bus-device
 *     License: GPLv2 or later
 *
 *      Author: Copyright (C) Max Gaukler <development@maxgaukler.de>
 *
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
 */
#include <avr/wdt.h>

#include "./main.h"

#include "./io.h"
#include "./uart.h"
#include "./task_hopper.h"

#define LED_DDR DDRB				// Hier DDR der Test-LED einstellen!
#define LED_PORT PORTB				// Hier PORT der Test-LED einstellen!
#define LED_AMBER_PIN PB0				// Hier PIN der Test-LED einstellen!
#define LED_BLUE_PIN PB1
#define LED_AMBER(x) out(LED_PORT,LED_AMBER_PIN,0,x)	// DO NOT CHANGE
#define LED_BLUE(x) out(LED_PORT,LED_BLUE_PIN,0,x)	// DO NOT CHANGE




uint8_t hexNibbleToAscii(uint8_t x);
uint8_t asciiToHex(uint8_t high, uint8_t low);

void __attribute__((noreturn)) fatal_real(const char * PROGMEM str, uint8_t d) {
	uartPC_tx_pstr(PSTR("\nFATAL: "));
	uartPC_tx_pstr(str);
	uartPC_tx_blocking(hexNibbleToAscii(d>>4));
	uartPC_tx_blocking(hexNibbleToAscii(d&0xF));
	uartPC_tx_blocking('\n');
	while (1) {}
}

#include "databuf.h"

typedef enum { CONSTANT, BLINK, TIMEOUT } rgb_mode_enum;
rgb_mode_enum rgb_led_mode[2] = {TIMEOUT, TIMEOUT};
uint8_t rgb_led_red[2] = {100, 100};
uint8_t rgb_led_blue[2] = {100, 100};
uint8_t rgb_led_green[2] = {100, 100};
uint32_t rgb_led_timer[2]= {0, 0}; 


rgb_mode_enum asciiToRGBMode(uint8_t x);


uint8_t asciiNibbleToHex(uint8_t ascii) {
	if (('0' <= ascii) && (ascii <= '9')) {
		return ascii-'0';
	} else if (('A' <= ascii) && (ascii <= 'F')) {
		return ascii-'A'+10;
	} else {
		FATAL_h("invalid hexstring",ascii);
		return 0;
	}
}

uint8_t asciiToHex(uint8_t high, uint8_t low) {
	return (asciiNibbleToHex(high) << 4) | asciiNibbleToHex(low);
}

uint8_t hexNibbleToAscii(uint8_t x) {
	if (x<10) {
		return '0'+x;
	} else if (x<16) {
		return 'A' + x - 10;
	} else {
		FATAL("hex too large");
		return 0;
	}
}


void task_comm(void) {
	static databuf cmd, resp; // initialised to zero because they are static variables, otherwise databufReset(&cmd), ...(&resp) would have to be called! see http://stackoverflow.com/a/4081193
	
	static uint8_t cmdBytesSent=0;
	static uint8_t respChk=0;
	static uint8_t respLen=0;
	static uint8_t timeout=0;

	static enum {READ_CMD, PROCESS_MDB_CMD, PROCESS_EXTENSION_CMD, READ_MDB_RESP, SEND_RESP_TO_PC}
		state = READ_CMD;
	
	LED_BLUE(state != READ_CMD); // state busy	
	switch (state) {
		case READ_CMD: // get command from PC
			if (uartPC_rx_ready()) {
				uint8_t d=uartPC_rx();
				// uartPC_tx_blocking(d); // als "loopback" test - PC-Software ist nicht dafür gedacht, also nur für händisches Testen einkommentieren
				if (d=='\r' || d=='\n') {
					if (hasData(&cmd) && (peekData(&cmd) == 'X')) {
						state = PROCESS_EXTENSION_CMD;
					} else {
						state=PROCESS_MDB_CMD;
					}
					cmdBytesSent=0;
				} else {
					storeData(&cmd,d);
				}
			}
			break;
		case PROCESS_EXTENSION_CMD:
		case PROCESS_MDB_CMD: // send command to device
			if (uartPC_rx_ready() || uartBus_rx_ready()) {
				FATAL("rx while SEND CMD");
			}
			if (state == PROCESS_MDB_CMD) {
				if (uartBus_tx_ready()) {
					if (hasData(&cmd)) {
						// send databyte. set bit8 if it is the first byte
						uartBus_tx(readAsciiHexbyte(&cmd), (cmdBytesSent==0));
						cmdBytesSent++;
					} else {
						databufReset(&cmd);
						// response R:<hexdata>
						storeData(&resp,'R');
						storeData(&resp,':');
						state=READ_MDB_RESP;
						respChk=0;
						respLen=0;
						timeout=0;
					}
				}
			} else if (state == PROCESS_EXTENSION_CMD) {
				readData(&cmd); // discard "X"
				uint8_t tmp = readData(&cmd);
				if (tmp == 'L') {
					/**
					 * LED Protocol:
					 * 
					 * command: LrrggbbMrrggbbM
					 * where rr, gg, bb are hex numbers 00...FF for the red/green/blue intensity
					 * and M is the LED mode, N for normal always on, B for blinking, T for timeout = switch-off after ca. 20 seconds
					 * 
					 * the first block rrggbbM is for LED 0, the second for LED 1
					 */
					// LED command
					for (uint8_t i=0; i<=1; i++) {
						rgb_led_red[i] = readAsciiHexbyte(&cmd);
						rgb_led_green[i] = readAsciiHexbyte(&cmd);
						rgb_led_blue[i] = readAsciiHexbyte(&cmd);
						rgb_mode_enum newMode = asciiToRGBMode(readData(&cmd));
						if (!((rgb_led_mode[i] == newMode) && (rgb_led_mode[i] == BLINK)))  {
							// reset timer, but not for an unchanged blink mode (then the sequence looks stupid)
							rgb_led_timer[i] = 0;
						}
						rgb_led_mode[i] = newMode;
					}
					if (hasData(&cmd)) {
						FATAL("extra data at end of LED cmd");
					}
					storeData(&resp, 'R');
					storeData(&resp, ':');
					storeData(&resp, 'O');
					storeData(&resp, 'K');
					state = SEND_RESP_TO_PC;
				} else if (tmp == 'H') {
					/**
					 * Hopper Protocol:
					 * 
					 * command: H
					 * 
					 * response:
					 * A  = ACK: command received, starting a dispense operation, please resend to poll for the result
					 *  B = busy, please resend command until you receive something else than busy (must not take more than 3 seconds)
					 *  E01  = out of service because of a serious error #01.
					 *         01 is the hexadecimal error number from hopperErrorEnum in task_hopper.h
					 *         Please reset board to exit this state, otherwise all hopper requests will be ignored and answered with this error.
					 *  RD = okay, dispensed a coin
					 *  RE = okay, hopper is empty, could not dispense a coin
					 */
					// hopper command (PC repeats this until the reply is not "busy")
					storeData(&resp, 'R');
					storeData(&resp, ':');
					if (hopper_get_error() != HOPPER_OKAY) {
						storeData(&resp, 'E'); // error, will not payout any coins anymore.
						storeHexNibbleAsAscii(&resp, (uint8_t) hopper_get_error());
					} else if (hopper_busy()) {
						storeData(&resp,'B'); // busy, please request again.
					} else if (hopper_has_response()) {
						storeData(&resp,'R');
						storeData(&resp, hopper_get_response());
					} else {
						hopper_request_dispense();
						storeData(&resp, 'A'); // ACK
					}
					state = SEND_RESP_TO_PC;
				} else {
					FATAL("invalid extension cmd");
				}
			}
			break;
		case READ_MDB_RESP: // receive response from device, send ACK
			if (uartPC_rx_ready()) {
				FATAL("rx0 while READ RESP");
			}
			if (uartBus_rx_ready()) {
				timeout=0;
				uint16_t d=uartBus_rx();
				respLen++;
				storeHexNibbleAsAscii(&resp, d);
				
				if (d&(1<<8)) { // bit8 is set - this is the end of the response
					uint8_t okay=0;
					uint8_t receivedNAK=0;
					state=SEND_RESP_TO_PC;
					if (respLen==1) {
						if (d==0x100) {
							okay=1; // ACK
						} else if (d==0x1FF) {
							// NAK empfangen - nicht mit NAK antworten!
							receivedNAK=1;
						} else {
							// Unsinn empfangen
						}
						okay = (d == 0x100); // ACK empfangen?
					} else {
						// answer contains data - validate checksum
						okay = ((d & 0xff) == respChk);
					}
					
					if (okay) {
						if (respLen>1) {
							// ACK nur wenn die Gegenstelle mehr zu sagen hatte als "ACK"
							uartBus_tx(0x00,0); // ACK
						}
					} else {
						databufReset(&resp);
						storeData(&resp,'R');
						if (receivedNAK) {
							// NAK empfangen - nicht mit NAK antworten!
							storeData(&resp,'N');
						} else {
							storeData(&resp,'E');
							uartBus_tx(0xFF,0);
						}
					}
				}
				
				respChk += (d&0xFF);

			} else {
				// uartBus_rx not ready
				timeout++;
				if (timeout >= 50) {
					// took longer than 50ms/TICKS_PER_MS ~= 8ms
					databufReset(&resp);
					storeData(&resp,'R');
					storeData(&resp,'T');
					state=SEND_RESP_TO_PC;
				}
			}
			break;
		case SEND_RESP_TO_PC: // send response to PC
			if (uartPC_rx_ready() || uartBus_rx_ready()) {
				FATAL("rx while sending");
			}
			if (uartPC_tx_ready()) {
				if (hasData(&resp)) {
					uartPC_tx(readData(&resp));
				} else {
					uartPC_tx('\n');
					databufReset(&resp);
					state=READ_CMD;
				}
			}
			break;
		default:
			FATAL("unknown state");
	}
}

void init_timer(void) {
	TCCR0A = (1 << COM0A1) | (1 << COM0B1) | (1 << WGM00); // non-inverting fast PWM
	TCCR0B = (1 << CS01); // use system clock / 8
	
	TCCR2A = (1 << COM2A1) | (1 << COM2B1) | (1 << WGM20); // non-inverting fast PWM
	TCCR2B = (1 << CS21); // use system clock / 8

	// Timer1 is 16bit and a little different
	// 8bit *inverting* fast PWM
	// WORKAROUND: Atmel fast PWM does not go down to 0%, but still outputs a narrow spike at 0.
	// 255 = 100% is possible, so we use inverted mode.
	TCCR1A = (1 << COM1A0) | (1 << COM1A1) | (1 << COM1B0) | (1 << COM1B1) | (1 << WGM10); // non-inverting fast PWM
	TCCR1B = (1 << WGM12)  | (1 << CS11); // use system clock / 8
	TIFR1 = (1<<TOV1); // clear overflow on first run
}

// set RGB LED no. $index
void rgb_set_pwm(uint8_t index, uint8_t r, uint8_t g, uint8_t b, uint8_t alpha) {
	r=(r*alpha)>>8;
	g=(g*alpha)>>8;
	b=(b*alpha)>>8;
	if (index == 1) {
		OCR2A=r;
		OCR0A=g;
		OCR0B=b;
	} else {
		OCR1B=255-r; // inverted PWM mode! see init_timer()
		OCR1A=255-g; // inverted PWM mode! see init_timer()
		OCR2B=b;
	}
}

/************************************
 * RGB LED
 ***********************************/

rgb_mode_enum asciiToRGBMode(uint8_t x) {
	if (x=='N') {
		return CONSTANT;
	} else if (x=='B') {
		return BLINK;
	} else if (x=='T') {
		return TIMEOUT;
	} else {
		FATAL("invalid LED mode");
		return CONSTANT;
	}
}

void task_rgb_led(void) {
	// slow down blinking / fadeout by 2^(n+1). n=0 means 2*255/TICKS_PER_MS = 80 milliseconds 
	const uint8_t BLINK_FREQUENCY_DIVIDER=3;
	const uint8_t TIMEOUT_FADEOUT_DIVIDER=4;
	
	const uint8_t TIMEOUT_SECONDS = 20; // how many seconds until fadeout?
	
	const uint32_t FADEOUT_START= TIMEOUT_SECONDS * (uint32_t)TICKS_PER_S;
	
	// save CPU time by only processing one RGB channel per task call
	// this slows down the LED update rate by factor 2
	static uint8_t index = 0;
	index = !index;
	uint8_t alpha=255;
	
	switch (rgb_led_mode[index]) {
		case CONSTANT:
			alpha=255;
			break;
		case BLINK:
			rgb_led_timer[index]++;
			if (rgb_led_timer[index] < (256 << BLINK_FREQUENCY_DIVIDER)) {
				alpha=rgb_led_timer[index]>>BLINK_FREQUENCY_DIVIDER;
			} else {
				alpha=255-(rgb_led_timer[index]>>BLINK_FREQUENCY_DIVIDER);
			}
			if (rgb_led_timer[index] >= ((255+256) << BLINK_FREQUENCY_DIVIDER)) {
				rgb_led_timer[index]=0;
			}
			break;
		case TIMEOUT:
			if (rgb_led_timer[index] < FADEOUT_START) {
				// phase 1: stay on fully
				rgb_led_timer[index]++;
				alpha = 255;
			} else if (rgb_led_timer[index] < FADEOUT_START + (255 << TIMEOUT_FADEOUT_DIVIDER)) {
				// phase 2: slowly fade to black
				rgb_led_timer[index]++;
				alpha = 255 - ((rgb_led_timer[index] - FADEOUT_START) >> TIMEOUT_FADEOUT_DIVIDER);
			} else {
				// phase 3: stay off
				alpha = 0;
			}
			break;
	}
	rgb_set_pwm(index, rgb_led_red[index], rgb_led_green[index], rgb_led_blue[index], alpha);
}








void sleep_remaining_time(void) {
	if (TIFR1 & (1<<TOV1)) {
		FATAL("time overrun");
	}
	LED_AMBER(1); // idle
	while (!(TIFR1 & (1<<TOV1))) {
		// wait until timer overflow
	}
	LED_AMBER(0);
	TIFR1 = 1 << TOV1; // reset overflow flag for the next time
	if (TIFR1 & (1<<TOV1)) {
		FATAL("TOV reset err");
	}
}

int main(void) {
	const uint8_t TEST=0;
    uint8_t mcusr_copy = MCUSR;
    MCUSR = 0;
	if (!TEST) {
		wdt_enable(WDTO_120MS);
	}
	LED_DDR |= (1<<LED_AMBER_PIN) | (1<<LED_BLUE_PIN); 		// setting LED-PIN to output
	LED_PORT |= (1<<LED_AMBER_PIN);
        
	uartPC_init();
	uartBus_init();
        hopper_init();
	// UART DDRs:
	DDRD |= (1<<PD3) | (1<<PD1);
        
        
        // RGB LEDs switched on at start, later overriden by timer PWM output
        DDRD |= (1<<PD4) | (1<<PD5) | (1<<PD6) | (1<<PD7);
//  	PORTD |= (1<<PD4) | (1<<PD5) | (1<<PD6) | (1<<PD7);
        DDRB |= (1<<PB3) | (1<<PB4);
//           PORTB |= (1<<PB3) | (1<<PB4);
        init_timer();
	// send one byte so that txReady() works
	uartPC_tx('\n');
	uartBus_tx(0xFF,1);
	
	if (TEST) {
		LED_PORT ^= (1<<LED_AMBER_PIN);
		delayms(1000);
		LED_PORT ^= (1<<LED_AMBER_PIN);
		delayms(1000);
		
		uartPC_tx_pstr(PSTR("TEST active\n"));     
		while (1) {
 			LED_PORT ^= (1<<LED_AMBER_PIN);
			if (uartPC_rx_ready()) {
				uint8_t d=uartPC_rx();
				uartPC_tx_pstr(PSTR("RX:"));
				uartPC_tx_blocking(d); 
				uartPC_tx_blocking('\n'); 
			} else {
				//uartPC_tx_pstr(PSTR("."));
			}
		}
	}
	
	uartPC_tx_pstr(PSTR("INFO:booting."));
	if (mcusr_copy & (1<<JTRF)) {
        uartPC_tx_pstr(PSTR("(JTAG reset)"));
    }
    if (mcusr_copy & (1<<WDRF)) {
        uartPC_tx_pstr(PSTR("(Watchdog or previous fatal error)"));
    }
	if (mcusr_copy & (1<<BORF)) {
        uartPC_tx_pstr(PSTR("(Brownout)"));
    }
    if (mcusr_copy & (1<<EXTRF)) {
        uartPC_tx_pstr(PSTR("(external reset)"));
    }
    if (mcusr_copy & (1<<PORF)) {
        uartPC_tx_pstr(PSTR("(power-on)"));
    }
    uartPC_tx_blocking('\n');
    init_timer(); // reset timer to prevent overrun at first loop
	while(1) {
		wdt_reset();
                // ATTENTION, no delays allowed in this loop.
		// fixed loop runtime is (0xFF * timer1 prescaler)/F_CPU = 170µs with prescaler=8 and F_CPU=12MHz
		// sleep_remaining_time() eats the remaning time.
		// UART buffer overruns would occur at a runtime of more than 8bit/(38.4kbit/s)=208µs
		
                task_comm();
		task_rgb_led();
		// TODO hopper untested
#warning TODO hopper disabled
		//task_hopper();
		
                // TODO sleep for...
                sleep_remaining_time();
	}
	return 0;
}

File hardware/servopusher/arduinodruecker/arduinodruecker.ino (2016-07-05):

#include <Servo.h>

Servo myservo;  // create servo object to control a servo
               // a maximum of eight servo objects can be created

int pos_wait = 0; // where should the servo start?
int pos_press = 90; // till where should the servo turn? minus for other direction
int wait = 2000; // how long should the servo wait in the end positions
int button = 7;  // The button is connected to PIN 7
int led = 5; // The LED in the button is connected to PIN 5

// connections:
// SERVO: yellow to PIN 9, other two are plus and GND
// button: black: GND
//         orange: GND
//         yellow: button to PIN7
//         red: LED to PIN 5


void setup()
{
  myservo.attach(9);  // attaches the servo on pin 9 to the servo object
  pinMode(button, INPUT);
  digitalWrite (button, HIGH);
  pinMode(led, OUTPUT);
  digitalWrite(led, LOW);
}

void loop()
{
  myservo.write(pos_wait); 
  if (digitalRead(button) == LOW) {
    digitalWrite(led, HIGH);
    myservo.write(pos_press);
    delay(wait);
    myservo.write(pos_wait);
    delay(wait);
    digitalWrite(led,LOW);
  }
}

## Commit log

2014-09-28 Hardware für Board hinzugefügt, fixes #1
    [mdb-interface.csv, mdb-interface.dsn, mdb-interface.kicad_pcb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]
2014-09-28 grundlegende Konfiguration, um das Board verwenden zu können
2014-09-28 repair DDRs and UART definitions. Fixes #2.
    [main.c]
2014-09-29 Fuse for 12V determined, fixes #5
2014-10-10 fix UART
2015-01-18 added missing footprint
2015-01-18 MDB_MR PULL-Up statt Pull-Down. fixes #10 falls die Diode passt
    [mdb-interface.sch]
2015-01-18 lötbrücke für 5V hinzugefügt, fixes #13
    [mdb-interface.sch]
2015-01-18 extra GND Pin, fixes #12
    [mdb-interface.sch]
2015-01-18 added schematic symbol for PNP with swapped leads, fixes #9
    [mdb-interface.sch]
2015-01-18 version bump
    [mdb-interface.sch]
2015-01-18 Leiterplattenbemaßung gesäubert, fixes #14
    [mdb-interface.kicad_pcb, mdb-interface.sch]
2015-01-18 Platine angepasst, bereit zur Fertigungsvorbereitung, fixes #11
    [mdb-interface.kicad_pcb, mdb-interface.sch]
2015-01-19 Platine aktualisiert: DRC stimmt jetzt für multi-cb und hat TOP/BOTTOM-Markierung
    [mdb-interface.kicad_pcb]
2015-01-26 Gerber-Daten erzeugt
    [mdb-interface.kicad_pcb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]
2015-01-27 Gerber erzeugt
    [mdb-interface.kicad_pcb]
2015-01-27 zip-Archiv der gerber-Daten
2015-01-27 Bohrprogramm hat gefehlt
    [mdb-interface.drl]
2015-04-20 RGB LED auf dauer-an
2015-05-02 moved mdb-interface to subdirectory
    [mdb-interface.csv, mdb-interface.dsn, mdb-interface.kicad_pcb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]
2015-05-03 first draft of connection interface to hopper
    [hopper-connector.sch]
2015-05-03 circuit now with better couplers and fuse
    [hopper-connector.sch]
2015-05-05 first real version of schematic
    [hopper-connector.sch]
2015-05-05 added profet status line to connector to mdb-board
    [hopper-connector.sch]
2015-05-05 add directory for the servopusher for the coin-device
    [servopusher.sch]
2015-05-05 servopusher laser files added
2015-05-05 updated parts to be SMDable
    [hopper-connector.sch]
2015-05-05 added notice on how to connect to MDB-interface
    [hopper-connector.sch]
2015-05-09 LED and hopper extension commands
2015-05-09 small improvements to LED and hopper
2015-05-12 fix LEDs, disable hopper because it is untested
    [main.c]
2015-06-14 fixed some issues with schematic
    [hopper-connector.sch]
2015-06-14 added attiny to schematic
    [servopusher.sch]
2015-06-15 minor fixes in schematic for Reichelt-order
    [hopper-connector.sch]
2016-06-17 ADD arduinofiles for the servopusher
2016-07-04 add the faceplate for the unlocking-button
2016-07-05 Servodrehung angepasst
2017-05-25 Troubleshoot MDB resets: Print reset cause, set lower brownout level
    [main.c]
2017-05-25 MDB Interface Platine: Änderungsnotiz zu 5V-Versorgung
    [mdb-interface.sch]

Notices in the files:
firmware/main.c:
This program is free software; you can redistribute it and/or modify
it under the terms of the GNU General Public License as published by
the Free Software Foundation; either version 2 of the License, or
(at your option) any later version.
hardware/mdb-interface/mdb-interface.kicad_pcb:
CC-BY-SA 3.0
